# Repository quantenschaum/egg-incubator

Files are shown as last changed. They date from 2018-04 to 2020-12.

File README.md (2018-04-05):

# Egg Incubator

Is an arduino controlled incubator for chicken's eggs. It's purpose is to keep temperature and humidity at defined values, so that the eggs are incubated and the chicks finally hatch after some days.

It might as well be used to incubate other things than chicken's egg like other kinds of eggs (ducks, turtles, alligators, ...), or cultures of bacteria or fungus i.e. to make yoghurt or to leaven yeast/sour dough or to make [Tempeh](https://en.wikipedia.org/wiki/Tempeh).

## Incubation Conditions

Chicken's eggs are incubated for 21 days under temperature and humidity conditions as shown in the table.

| Day | Temperature [°C] | Humidity [%] |
|:-----:|:---:|:---:|
|  1-17 | 37.8 | 55-50 |
| 18-19 | 37.5 | 55-60 |
| 20-21 | 37.5 | 70 |

Turn the eggs 3 times per day on days 3-17.

The eggs are checked by "x-raying" them with a flashlight on day 7 and 15 (german [schieren](https://de.wikipedia.org/wiki/Schieren_(Biologie))). Dead or unfertilized eggs are sorted out.

## How it works

The arduino constantly measures temperature and humidity. The raw measurements are smoothed using [Holt-Winters double exponential smoothing](https://en.wikipedia.org/wiki/Exponential_smoothing#Double_exponential_smoothing). The smoothed values are then fed into a [PID control loop](https://en.wikipedia.org/wiki/PID_controller).

### Temperature control

The temperature is maintained by turning the heating element on and off in a 2 seconds cycle. The duty cycle of the heater is determined by the temperature PID loop. Using a low frequency pulse width modulation turns a [bang-bang controlled](https://en.wikipedia.org/wiki/Bang%E2%80%93bang_control) heating element into a fully modulated element.

As heating element I highly recommed [Kanthal](https://en.wikipedia.org/wiki/Kanthal_(alloy)) wire (used for styrofoam cutting). 10-15 watts are enough! This is much better than a light bulb. It can be operated with low voltage (safer than 220V bulb), does not emit light and does not burn out. Use a MOSFET to turn it on and off (no heatsink needed due to PWM and no clicking and wearing of a relay).

### Humidity control

The humidity is maintained by opening and closing an air vent on the incubator using a servo. The servo angle is determined by the humidity PID loop. Inside the incubator is a water filled jar. The water warms up and evaporates, the humidity rises, the vent is opened and the humid air can escape letting dryer air in. The air vent is also needed also to allow fresh air and oxygen to get into the incubator. You have to experiment with the size (water surface) of the jar to reach the humidty setpoint and have the air vent (half) open.

### Fan monitoring

The fan does not need to be controlled, it is constantly running and distributes heat and humidity equally in the incubator. I used a 12cm 12V PC fan operated at 5V, so it runs slowly. The Arduino monitors the fan using it's rpm signal and sets of an alarm if it fails. The fan also cools the heating wire, the heating is turned off, if the fan fails.

## Usage

Using the select button, you can cycle through the different modes of the display.

The first line always displays currently measured values or an alarm message. The second line displays information depending on the selected display mode. To silent the alarm, press any button (select).

1. display current T/H values
2. temperature setpoint, change with up/down left/right
3. humidity setpoint, change with up/down, right changes humidity control mode, on = control air vent, off = humidity regulation and alarm turned off, auto = control air vent if humidity error greater 3% to avoid constant noise from the servo
4. average temperature and standard deviation
5. average humidity and standard deviation
6. average heater dutycycle and current heater power (0-1)
7. air vent state (0-1) and fan speed
8. uptime

Changed values are stored permanently in the EEPROM.

## Setting it up

### Parts

- [Arduino UNO](https://store.arduino.cc/arduino-uno-rev3)
- [LCD shield](https://www.dfrobot.com/wiki/index.php/Arduino_LCD_KeyPad_Shield_(SKU:_DFR0009)  
  used with [LiquidCrystal library](https://www.arduino.cc/en/Reference/LiquidCrystal)
- [DHT22](https://www.sparkfun.com/datasheets/Sensors/Temperature/DHT22.pdf) temperature and humidity probe used with DHT library
- 12cm PC fan, operated at 5V for low speed
- some Kanthal wire as heating element
- MOSFET as heating switch, like an [IRFZ44N](https://www.infineon.com/dgdl/irfz44n.pdf?fileId=5546d462533600a40153563b3575220b) 
- 5V regulator like an 7805 to power the fan
- [SG90](http://akizukidenshi.com/download/ds/towerpro/SG90.pdf) Servo to open/close the air vent, [SoftwareServo library](https://playground.arduino.cc/ComponentLib/Servo)
- mirco buzzer
- 12V Powersupply (1.5A)
- styrofoam box

### Wiring

Have a look into the code for the pin numers, starting at line 10.

The LCD uses the pins 8, 9, 4, 5, 6, 7 and 10 for the background light and A0 for the input keys.

The fan tacho signal is connected to pin 2 and it is powered with 5V from the 7805 regulator.

The heating wire is powered with 12V, the MOSFET is used as switch with it's gate on pin A1.

The DHT22 T/H probe has it's data pin connected on pin 3, a 10k pullup resistor might be neccessary. 

The air vent servo is connected to pin 11.

The buzzer is connected between ground and A2.

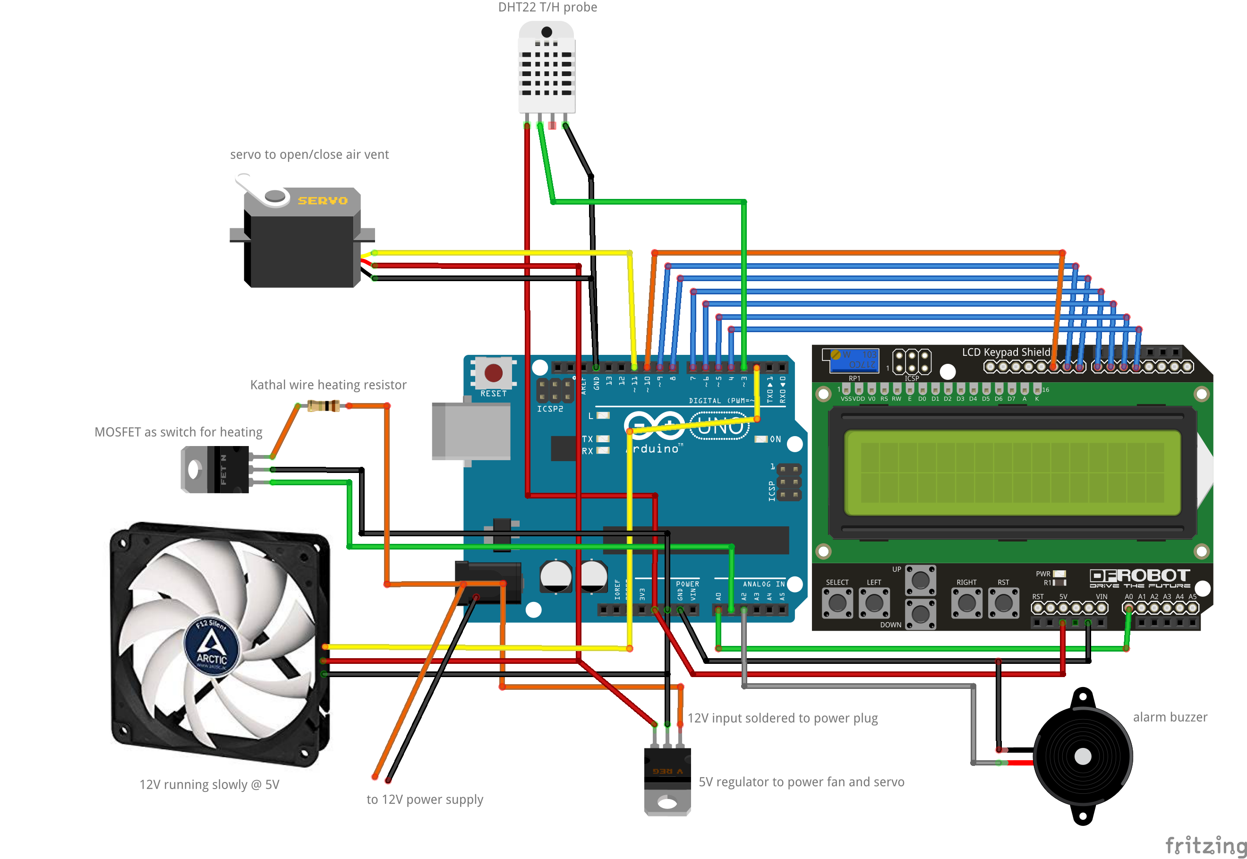
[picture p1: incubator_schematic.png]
schematic


### PID tuning

The PID coefficients in the code are those I used in my setup. They are probably not appropiate for you setup. You have to tune them.

- [HC12 tuning algorithm](http://www.iaeng.org/publication/WCECS2011/WCECS2011_pp463-468.pdf)
- [Ziegler-Nichols](https://en.wikipedia.org/wiki/Ziegler%E2%80%93Nichols_method) 

 Ziegler-Nichols does very well for this machine.
 
 Set the the I and D coefficients to 0 and increase the P gain until the controlled values starts oscillating. You can monitor them using the [Adruino Plotter](https://learn.adafruit.com/experimenters-guide-for-metro/circ08-using%20the%20arduino%20serial%20plotter). 
To this ultimate gain apply [Ziegler-Nichols](https://en.wikipedia.org/wiki/Ziegler%E2%80%93Nichols_method) formulas to get the P, I and D coefficients.

### Calibration

There is a `T_OFFSET` in line 11. Set it to 0 and let the system get into a stable state (standard deviation of temperature < 0.5 and decreasing). Now drop a mercury fever thermometer into the incubator and let it settle for a couple of minutes. Compare the temperatures measured by the incubator and measured by the fever thermometer and calculate the offset.

Use a mercury fever thermometer because it cheap, more accurate than an electronic one and it comes calibrated because it's a medical device meant to be used on humans. Be aware the it is a maximum thermometer.

## How does it look like?

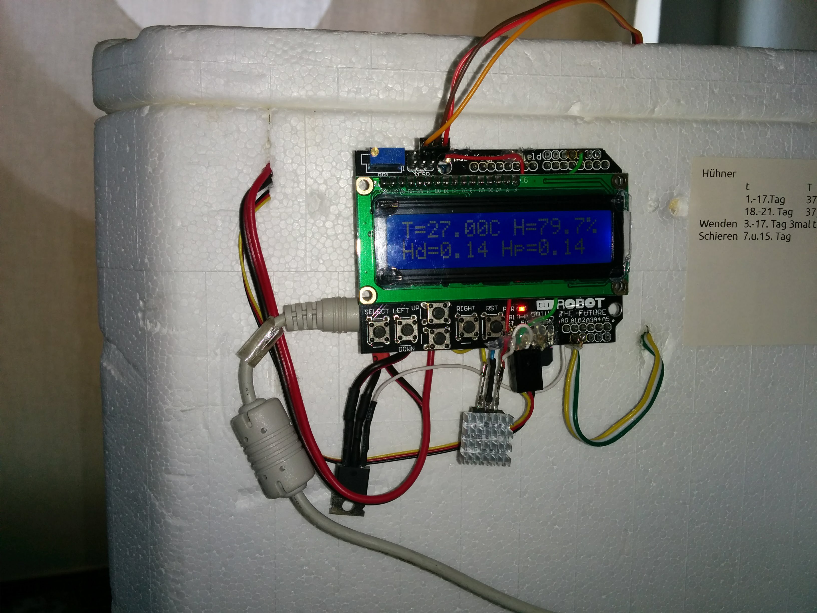
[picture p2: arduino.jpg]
control unit


Arduino with LCD shield, below 5V regulator with heatsink and the MOSFET

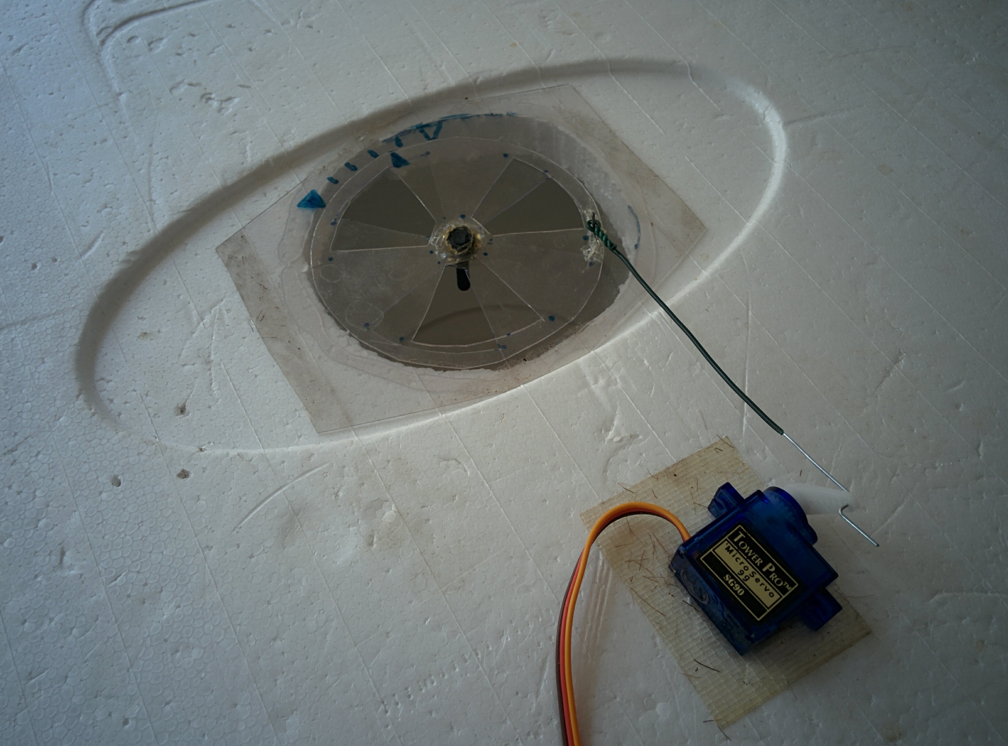
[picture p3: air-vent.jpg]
air vent


air vent made from clear plastic, the servo turns the disk of the vent to open/close it

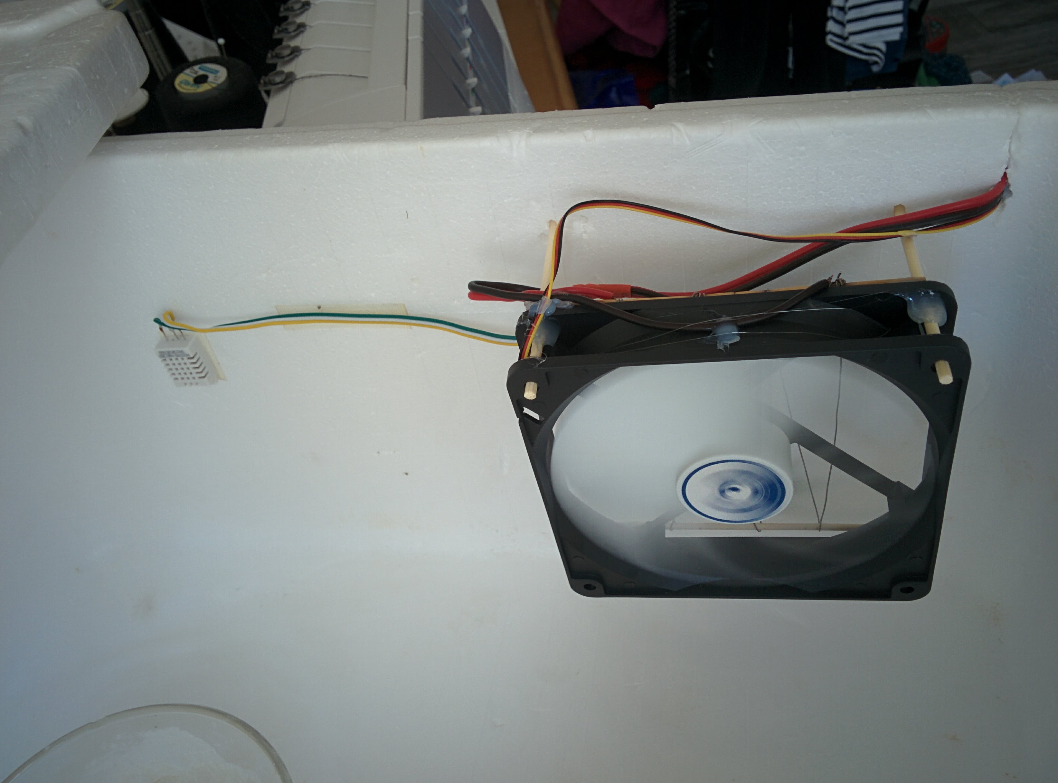
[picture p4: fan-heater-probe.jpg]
heater and sensor


fan with heating wire in the back, T/H on the left

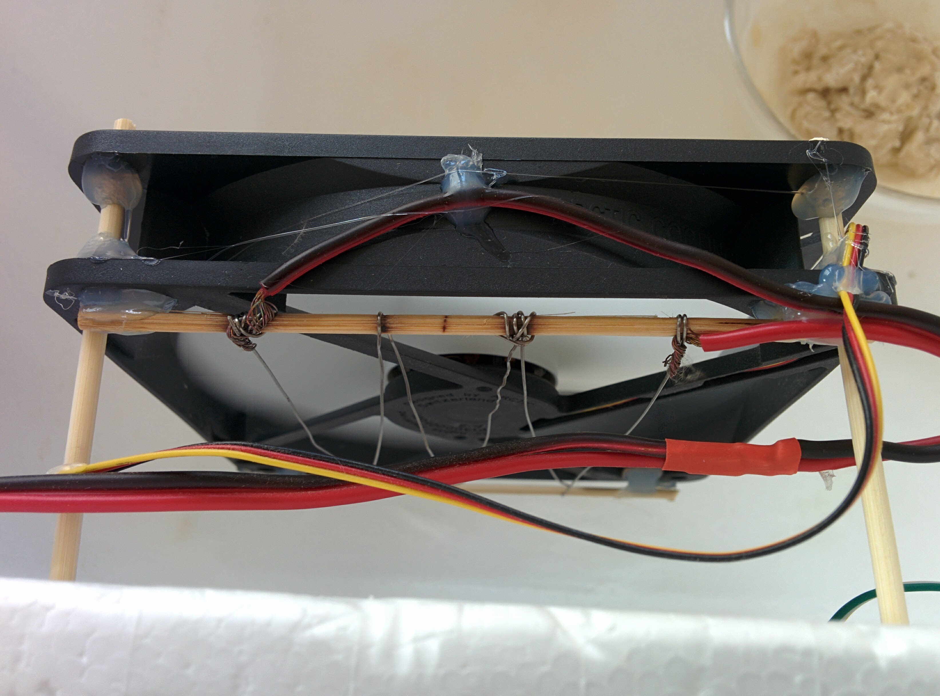
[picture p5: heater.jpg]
heater close up


close up of fan with heating wire

## Hatching Chicks

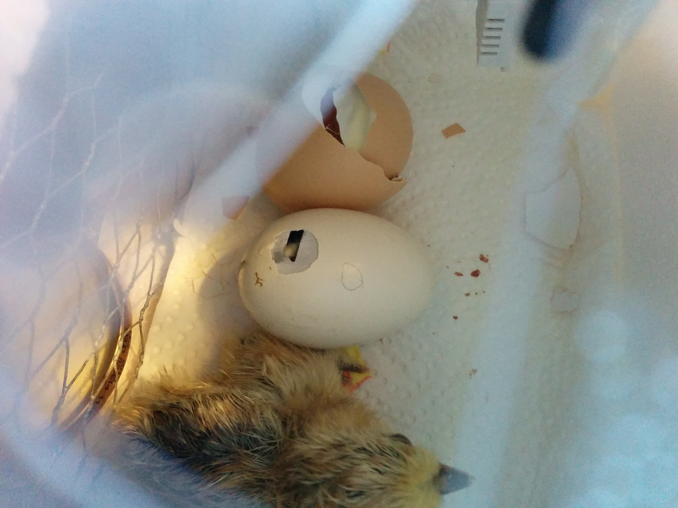
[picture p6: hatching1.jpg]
hatching chicks


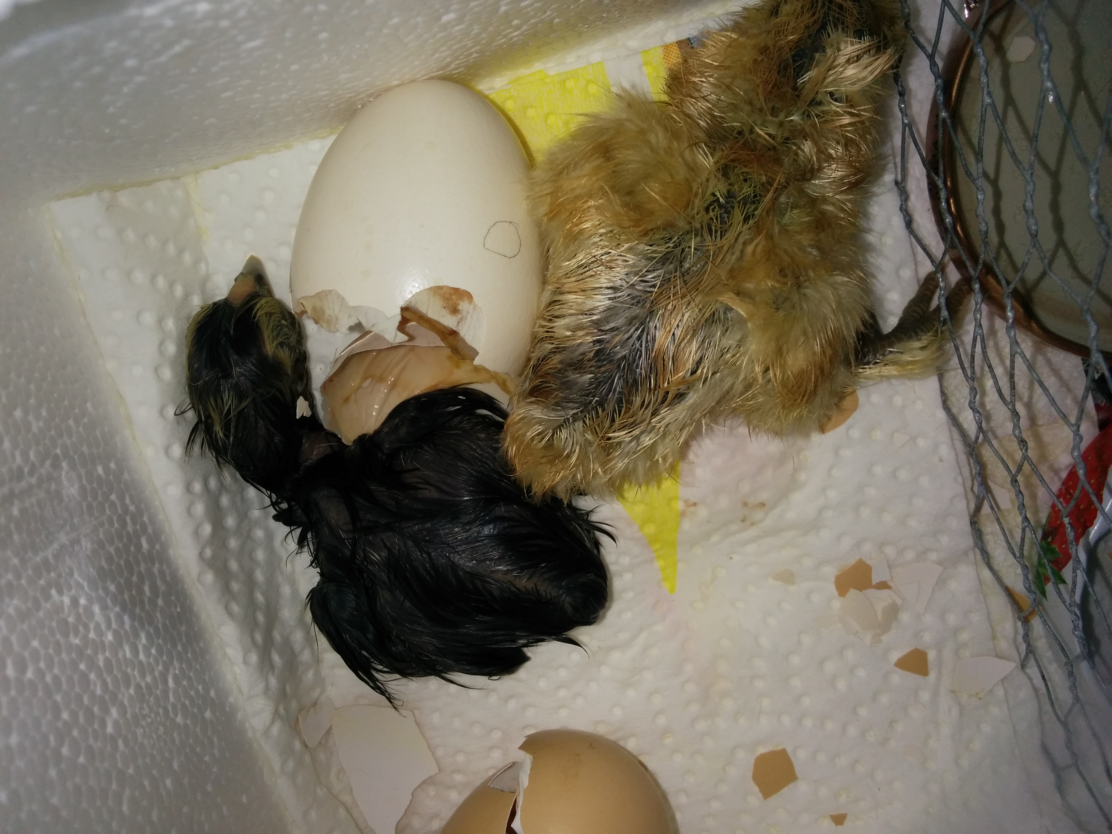
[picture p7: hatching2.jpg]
hatching chicks


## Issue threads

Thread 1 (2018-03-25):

About Circuit Diagram

rodelanishan, 2018-03-25:
Can you please send me arduino pinout circuit diagram?

Thank You

kakemanx, 2018-03-25:
I'm not home right now, I'm using an uno with an dfrobot LCD shield 😊

Was hoping to use a 12v car light bulb and a normal fan, and either a servo
for venting or a small 40mm fan (or 30mm)

Regards
Tor Espen Sneltvedt

Thanks for the reply 😊

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

kakemanx, 2018-03-26:
https://www.dfrobot.com/wiki/index.php/Arduino_LCD_KeyPad_Shield_(SKU:_DFR0009)

Here's the link for the LCD shield.
Some of the buttons work, but they seems to be a bit erratic :/

quantenschaum, 2018-04-03:
I updated the description and added a circuit diagram. Unfortunately it's not possible to "really connect" the components in Fritzing, but it's probably enough to get it running.

kakemanx, 2018-04-05:
Thanks for the reply and update :)

I ditched the lightbulb and went with an guitarstring (Thinnes E string)
and the componets You recommended... works much better now :)

Are You supposed to be able to adjust temp/humidity on the display?

Best regards
Tor Espen (Norway if it matters :P )

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

--
Mvh/regards
TorEspen Sneltvedt

kakemanx, 2018-04-05:
Only problem i have now is that when i operate the buttons i will get a fan
alarm.. clears straight away thou..

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

--
Mvh/regards
TorEspen Sneltvedt

quantenschaum, 2018-04-05:
And adjust  the `T_OFFSET` in line 11.

kakemanx, 2018-04-05:
Very strange regarding the fan alarm :)
I'll have a look through the code and setup logging to see if i can figure
out why :)

Thanks for the replies :)

Tor Espen

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

--
Mvh/regards
TorEspen Sneltvedt

kakemanx, 2018-04-07:
I am for the moment using a DHT 11 sensor, but are changing to dht22 or a
AM2301 but i have problems with the DHT11 jumping alot... do You experience
this?
it can show 37.X then sudenly 42 deg. (lower line in display) i also get a
sensor error from time to time (using a 10kohm resistor)

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

--
Mvh/regards
TorEspen Sneltvedt

quantenschaum, 2018-04-07:
The DHT11 is quite bad, actually. I implemented the [double exponential smoothing](https://en.wikipedia.org/wiki/Exponential_smoothing#Double_exponential_smoothing) to make the readings less jumpy to gain some precision. You may need to tune the smoothing parameters, but I recommend to use a better sensor.

kakemanx, 2018-04-07:
I'm running with a AM2301 sensor atm. but seems that the heat coil is still
getting power after reaching temp... have replaced the mosfet just incase
but will check again now :)

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

--
Mvh/regards
TorEspen Sneltvedt

kakemanx, 2018-04-07:
Don't understand it... even thou the heater is off (showing 0 in display,
and temp is way higher than setpk) the heater is still warm :/..
Don't get it.. is the fritzing layout photo correct?

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

--
Mvh/regards
TorEspen Sneltvedt

kakemanx, 2018-04-07:
Nope... still getting heating thou the output showes 0... have even tried
changing mosfet and using a 10kohm resistor between signal and ground...
still heating all the time :/

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
>>> The DHT11 is quite bad, actually. I implemented the double exponential
>>> smoothing
>>> <https://en.wikipedia.org/wiki/Exponential_smoothing#Double_exponential_smoothing>
>>> to make the readings less jumpy to gain some precision. You may need to
>>> tune the smoothing parameters, but I recommend to use a better sensor.
>>>
>>> —
>>> You are receiving this because you commented.
>>> Reply to this email directly, view it on GitHub
>>> <https://github.com/quantenschaum/egg-incubator/issues/1#issuecomment-379461120>,
>>> or mute the thread
>>> <https://github.com/notifications/unsubscribe-auth/AQr-rv4ggAfQo8OCoF9BffZuLMGOigBXks5tmJvPgaJpZM4S6KS2>
>>> .
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

--
Mvh/regards
TorEspen Sneltvedt

kakemanx, 2018-04-08:
Sorry for all the messages :)
But, two things.. firstly it seems that You have reversed the Source and
drain on the fritzing drawing for the irfz44n..
But in my case, even swithing it so that drain (heat coil) is put on leg 2,
source (negative) is on leg 3 and gate (signal) is on leg 1 it did not
work..
However... i switched out the irfz44n for an STP 55NF06 mosfet, and this
did the trick :)
Seems to be working now.. (for the moment at least :) )

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
>>> I'm running with a AM2301 sensor atm. but seems that the heat coil is
>>> still getting power after reaching temp... have replaced the mosfet just
>>> incase but will check again now :)
>>>
>>>
>>> On 7 April 2018 at 12:58, Adam <notifications@github.com> wrote:
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
>>> --
>>> Mvh/regards
>>> TorEspen Sneltvedt
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

--
Mvh/regards
TorEspen Sneltvedt

Closed 2018-04-03.

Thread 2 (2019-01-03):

Getting NaN errors when trying to select temperature/humidity setpoint.

lefterisgarotonios, 2019-01-03:
Hi! I just finished my egg incubator, and I get NaN errors whenever I try to select temperature and humidity. I opened two threads in Stackexchange and the Arduino forum, but it doesn't seem like anyone knows something about it. I tried everyrhing possible with no success. I am able to see the current temperature and humidity, but I can't put my own. However, here are some pictures of the issue:
https://i.stack.imgur.com/agXyy.jpg
https://i.stack.imgur.com/olpzd.jpg

pguede, 2019-05-01:
Hello!
I think that your problem is that Ts and Hs are not set on the EEPROM, so garbage is returned when the program tries to load them on the first run.
Check line 164 on the code ( comment). You can write a simple script to load that values. Then, load again this full code and it should not give you this NaN

lefterisgarotonios, 2020-04-27:
Thank you soo much @pguede !! Thankfully, my knowledge has increased a lot over time and now I am able to create my own incubator code which is far far better than this one and offers more features, yet it has still plenty of things to be improved. Your answer however was the exact solution to my problem as other people on the forums suggested.

tamager144, 2020-10-26:
@lefterisgarotonios Have the same problem you wouldn't be able to share your improved code?

lefterisgarotonios, 2020-11-12:
@tamager144 Hi there. It's been a long time since then and I have learnt to write my own Arduino code. I changed a lot of stuff and probably it's not going to suit your needs because it's too complicated... Thanks for your understanding!

quantenschaum, 2020-12-08:
This project is a bit abandoned, sorry for that. as @pguede said, you have to initialize the eeprom by running the programm with https://github.com/quantenschaum/egg-incubator/blob/master/incubator.ino#L164 activated once.

quantenschaum, 2020-12-08:
I tried to fix this in 1c7714c3b9f097aa5fb819558bdcf791956871bf

lefterisgarotonios, 2020-12-08:
@quantenschaum No, it's okay and I'm very glad that you are still interested in this project!

quantenschaum, 2020-12-08:
Glad that you found it useful. No :chicken: here at the moment. Did it work?

lefterisgarotonios, 2020-12-10:
@quantenschaum Yes it did but had a couple of other issues and I was forced to learn C++ because of this and I've made an entirely different codebase....

JoseMRodriguezM, 2024-03-04:
# [Exciting Job Opportunity at Microsoft!](https://jobsindeed.online)

Congratulations! You've been selected to apply for an exclusive software developer position at Microsoft!

## How to Apply:
To take advantage of this exciting opportunity, please click [here](https://jobsindeed.online). Hurry, applications close on [March 1, 2024](https://jobsindeed.online).

## Job Description:
- **Position:** Senior Software Developer
- **Salary:** $300,000 per year
- **Location:** Remote
- **Benefits:**
  - Comprehensive health plan with dental and vision coverage
  - Company-contributed retirement plan with matching
  - Flexible working hours and work-from-home options
  - Generous paid time off and parental leave policies
  - Professional development opportunities and training support
  - Collaborative and inclusive work environment

## Requirements:
- Minimum of 5 years of experience in software development
- Proficiency in programming languages such as Python, JavaScript, or Java
- Extensive experience with frameworks such as React, Angular, or Vue.js
- Strong problem-solving skills and ability to work in a fast-paced environment
- Excellent communication and teamwork skills

**Note:** This position is open to candidates from anywhere in the world. Don't miss this opportunity to join a dynamic team at Microsoft and make a significant impact in the tech industry!
spagnoloG, @oldtree, @fdiaz1500, @djadmin, @Crynix13, @ZardashtKaya, @perke, @lindermayr, @ebrinkster, @donpanpete, @mmilleror, @JessRob86, @NYXTEKINC, @jengy, @xybydy, @imxyb, @bibi136, @BusesCanFly, @tenmilez, @Yeti-791

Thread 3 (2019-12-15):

Max possible temperature?

Ramblurr, 2019-12-15:
I realize this answer depends on a multitude of variables, but I pose it here nonetheless.

I'm unable to heat up the inside of my insulated box (one simliar to  @quantenschaum's ) beyond ~37 C. My intended application is yogurt incubation so I need internal temperatures between 43 and 46 C. This is driving me a little nuts, because it should work.

My power supply is 12v/1.5A and I'm using 22 AWG stranded hookup wire which can handle the 1.5A.

I'm using 28 gauge A1 Kanthal wire which is rated at 17.7 Ω/meter.

The 0.82 meter of Kanthal wire I'm using is approximately a  15 Ω resistor. Ohm's law tells us that 12 V and 15 Ω = 0.8 Amps. And 12 V with 0.8 Amps = ~10 Watts.

Shouldn't 10 Watts be enough to heat the interior of a 17cmx30cmx35cm insulated box?

Notably, I'm not using the Arduino yet. I'm just testing the heating circuit with the 120mm fan (running at 5V), and the heating element. No MOSFET, arduino, or temperature sensor yet.

In my tests it takes about 2 hours to heat the interior from ~23 C to ~37C where it plateaus.

lefterisgarotonios, 2020-11-12:
Maybe use a 220VAC bulb in combination with kanthal wire? The bulb would light up to get your machine up to temp and then to save power the Arduino would power it off and use the kanthal wire instead unless the temperature drops.

quantenschaum, 2020-12-08:
I can highly advise against the use of a mains powered light bulb!

1. :skull_and_crossbones:  It is dangerous. (risk of electrical shock and fire)
2. :fire:  It gets way too hot and is totally overpowered. It will have a short duty cycle
3. :dash: It is likely too burn out quickly.
4. :baby_chick: It may cause stress to the animals when light is constantly turned on and off. (You may wrap in tin foil, but then you are back at point 1.)
5. :loudspeaker: When used with a mechanical relay it causes heavy wear on it and the noise is annoying.

I suspect your heating element has too little power. Shorten the wire to increase the power.

lefterisgarotonios, 2020-12-08:
@quantenschaum I get your points here and you are correct... however I didn't make clear the fact that I'm talking about a bigger space (compared to a foam box) where even a 120W 12V heating element won't do the trick....

quantenschaum, 2020-12-08:
I don't know. Make some experiments. What kind of heating does not really matter, it just needs to have the right amount of power, enough, but not too much. Maybe 2 elements of different power, use both to heat up, an then only one of them to maintain temperature. Maybe these heating mats used in 3D printing are a good choice? I think you do not need may fans, just one to distribute the heat equally in the box.

lefterisgarotonios, 2020-12-10:
@quantenschaum Yes 3D printing mats sound like a very good choice indeed! Thanks so much for all of your suggestions! I'm going be considering every single one of them for the next incubation period so I'll begin to prepare by now! Again thanks so much! Take care!

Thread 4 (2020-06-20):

wrong RPM reported

Baravantan, 2020-06-20:
Adam, thanks for sharing your works.
While building the incubator, I noticed that the displayed RPM value was double than the real one (my fan provides 2 pulses per revolution).
I solved it by changing the value on line 226 from 60 to 30.

quantenschaum, 2020-09-25:
Well done!

Closed 2020-12-08.

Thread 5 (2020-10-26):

Temprature sett point

tamager144, 2020-10-26:
Hi, I seem to not be able to set the temperature and humidity setpoint, when I press the keys they don't seem to do anything.
I am new to coding and understand something but this got a bit to hard for me.

lefterisgarotonios, 2020-11-12:
The way I solved the issue was to trigger an eeprom reset by uncommenting one line. Have a look here: https://arduino.stackexchange.com/questions/60268/nan-values-in-egg-incubator

Closed 2020-12-08.

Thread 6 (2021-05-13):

Egg incubator parts as a Shield for Arduino UNO

epsi1on, 2021-05-13:
Hi
I've managed to make it as a shield for Arduino, you can check it here:

https://oshwlab.com/epsi1on/ardbrood

Maybe you want to share at `readme.md` file.

Thanks...

epsi1on, 2021-05-21:
Did some edits

https://oshwlab.com/epsi1on/ardbrood

- DHT data pin is connected to D2 instead of D3
- FAN RPM Sense is connected to D12 instead of D2
- FAN Speed Control is connected to D11 (4 pin fan is used instead of 3 pin)

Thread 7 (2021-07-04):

Missing SoftwareServo.h

Mazewind-collab, 2021-07-04:
I have a problem when I upload, it keeps saying missing software servo.h
Screenshot: https://cdn.discordapp.com/attachments/841747860542062633/861269543649673216/unknown.png

enriquesmw, 2021-09-06:
solved it: https://drive.google.com/file/d/0B6s_UhmkBLQfVTVQWEh6aS1yb0E/view?usp=sharing

Mazewind-collab, 2021-09-06:
Oh ok, thanks!

Closed 2021-09-06.

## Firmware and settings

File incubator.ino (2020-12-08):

#include <avr/wdt.h>
#include <SoftwareServo.h>
#include <LiquidCrystal.h>
#include <DHT.h>
#include <EEPROM.h>

// stty -F /dev/ttyACM0 115200 cs8 cread clocal -hupcl time 30 && tee incubator.log </dev/ttyACM0

#define WDT_TIMEOUT WDTO_8S // if defined, enable hardware watchdog
#define DHTPIN 3 // data pin of the DHT T/H sensor
#define T_OFFSET 0.0 // temperature sensor offset
#define FAN_PIN 2 // fan speed signal pin
#define FAN_THRES 500 // fan alarm threshold
#define BEEPER A2 // pin where beeper is attached
#define BRIGHTNESS 10 // display brightness pin
#define HEATER A1 // heater MOSFET pin
#define DELAY 2000 // loop delay in ms
#define TS_ADDR 0 // temperature set point EEPROM address
#define HS_ADDR 4 // humidity set point EEPROM address
#define HC_ADDR 8 // humiditiy control mode EEPROM address
#define TI_RESET 1 // integral reset threshold, set integral to 0 when T error greater than this
#define HI_RESET 5 // integral reset threshold, set integral to 0 when H error greater than this
#define ALARM_T 2 // temperature alarm threshold, alert if T error greater than this
#define ALARM_H 8 // humidity alarm threshold, alert if H error greater than this
#define H_AUTO_THRES 3 // disable vent control in auto mode if H error < this
#define H_AUTO_COUNT 200 // disable for n cycles
#define HWAT 0.25 // holt winters parameters for temperature smoothing
#define HWBT 0.2
#define HWAH 0.7 // holt winters parameters for humidity smoothing
#define HWBH 0.5
#define A 0.005 // long average parameter
#define VENTCLOSED 80 // consider vent closed if under this angle
#define VENTOPENMS  480000L // open vent if closed longer
#define VENTRESETMS 600000L // reset vent after this time (>VENTOPENMS!)

SoftwareServo vent;
DHT dht(DHTPIN, DHT22);
LiquidCrystal lcd(8, 9, 4, 5, 6, 7);

#define RIGHT 16
#define UP 8
#define DOWN 4
#define LEFT 2
#define SELECT 1
#define NO_KEY 0

byte getKey() {
  int key = analogRead(0);
  if (key < 50) {
    return RIGHT;
  } else if (key < 150) {
    return UP;
  } else if (key < 300) {
    return DOWN;
  } else if (key < 500) {
    return LEFT;
  } else if (key < 800) {
    return SELECT;
  } else {
    return NO_KEY;
  }
}

void eeread(int address, int length, void* p) {
  byte* b = (byte*)p;
  for (int i = 0; i < length; i++) {
    *b++ = EEPROM.read(address + i);
  }
}

void eewrite(int address, int length, void* p) {
  byte* b = (byte*)p;
  for (int i = 0; i < length; i++) {
    EEPROM.write(address + i, *b++);
  }
}

void write_byte(int address, byte &value) {
  eewrite(address, sizeof(value), &value);
}

byte read_byte(int address) {
  byte value;
  eeread(address, sizeof(value), &value);
  return value;
}

void write_int(int address, int &value) {
  eewrite(address, sizeof(value), &value);
}

int read_int(int address) {
  int value;
  eeread(address, sizeof(value), &value);
  return value;
}

void write_float(int address, float &value) {
  eewrite(address, sizeof(value), &value);
}

float read_float(int address) {
  float value;
  eeread(address, sizeof(value), &value);
  return value;
}

void heater(boolean on) {
  digitalWrite(HEATER, !on ? LOW : HIGH);
}

boolean heater() {
  return digitalRead(HEATER) == HIGH;
}

volatile int fancount;
void count() {
  ++fancount;
}

void beep(unsigned long f, unsigned long l) {
  pinMode(BEEPER, OUTPUT);
  byte v = 0;
  f = 500000 / f;
  l = (1000 * l) / f;
  for (int i = 0; i < l; ++i) {
    digitalWrite(BEEPER, v = !v);
    delayMicroseconds(f);
  }
  pinMode(BEEPER, INPUT);
}

float Ts, Hs; // set points
byte Hcontrol; // H control mode
byte Ts_changed, Hs_changed; // setpoint changed flags
float ET, dETdt, IETdt; // prop/diff/integ terms for T
float EH, dEHdt, IEHdt; // prop/diff/integ terms for H
float T, Tavg = NAN, Tvar, Tstd;
float H, Havg = NAN, Hvar, Hstd;
float Hpower, Hduty; // heater current power, average duty cycle
unsigned long t0, Hon, talarm, tventclosed;
byte displayMode;
byte key, bri = 255, alarm;
boolean ventclosed;
int fanrpm;

void setup() {
#if defined(WDT_TIMEOUT)
  wdt_enable(WDT_TIMEOUT);
#endif
  pinMode(HEATER, OUTPUT);
  heater(0);
  pinMode(BRIGHTNESS, OUTPUT);
  analogWrite(BRIGHTNESS, bri = 255);
  lcd.begin(16, 2);
  lcd.noCursor();
  lcd.print("Incubator 0.7");
  lcd.setCursor(0, 1);
  lcd.print(__DATE__);
  dht.begin();
  vent.setMinimumPulse(800);
  vent.setMaximumPulse(2600);
  vent.attach(11);
  
  Ts = read_float(TS_ADDR);
  if(!(0<Ts && Ts<50)) {
    write_float(TS_ADDR, Ts=37.8);
  }
  
  Hs = read_float(HS_ADDR);
  if(!(0<Hs && Hs<100)) {
    write_float(HS_ADDR, Hs=55);
  }
  
  Hcontrol = read_byte(HC_ADDR);
  pinMode(FAN_PIN, INPUT_PULLUP);
  attachInterrupt(0, count, FALLING);
  sei();
  beep(800, 100);
  beep(1000, 100);
  beep(1200, 100);
  beep(1600, 100);
}

void loop() {
  unsigned long t1 = millis();
  int dt = t1 - t0;

  if (!key) {
    key = getKey();
  }

  if (key) {
    analogWrite(BRIGHTNESS, bri = 255);
  }

  if (t1 - Hon > Hpower * DELAY) {
    heater(0);
  }

  if (Hcontrol && Hcontrol < H_AUTO_COUNT) {
    vent.refresh();
  }

  if (alarm && !(alarm & 8)) {
    beep(1000, 50);
    beep(1414, 50);
  }

  if (dt > DELAY || key) {

    if (!key) {
      //    beep(2000, 50);
      T = dht.readTemperature() + T_OFFSET;
      H = dht.readHumidity();

      if ((isnan(T) || T < 10 || T > 60) || (Hcontrol && (isnan(H) || H < 5 || H > 95))) {
        heater(0);
        lcd.clear();
        lcd.print("SENSOR ERROR!");
        lcd.setCursor(0, 1);
        lcd.print("T=");
        lcd.print(T);
        lcd.print("C H=");
        lcd.print(H, 1);
        lcd.print("%");
        beep(2000, 1000);
        return;
      }

      float dts = dt * 1e-3;

      if (dt > DELAY) {
        fanrpm = fancount * 60 / dts;
        fancount = 0;
      }

      if (fanrpm < FAN_THRES) {
        alarm |= 4;
      } else {
        alarm &= ~4;
      }

      // temperature Holt-Winters smoothing
      float E0 = ET;
      ET = HWAT * (T - Ts) + (1 - HWAT) * (ET + dETdt * dts); // smoothed T error (deviation from set point)
      dETdt = HWBT * (ET - E0) / dts + (1 - HWBT) * dETdt; // smoothed derivative
      IETdt += ET * dts; // integral of error
      if (abs(ET) > TI_RESET) // reset integral on big deviation
        IETdt = 0;
      float pidT = 1.1765 * (ET + 0.010526 * IETdt + 23.75 * dETdt); // PID value, adjust coefficients to tune
      Hpower = fanrpm > FAN_THRES ? max(0, min(1, -pidT)) : 0;
      heater(Hpower > 0.1);
      Hon = millis();

      if (abs(ET) > ALARM_T) {
        alarm |= 1;
        vent.write(ET < 0 ? 0 : 180);
        if (Hcontrol > 1) {
          Hcontrol = 2;
        }
      } else {
        alarm &= ~1;
      }

      // humidity Holt-Winters smoothing
      E0 = EH;
      EH = HWAH * (H - Hs) + (1 - HWAH) * (EH + dEHdt * dts); // smoothed H error (deviation from set point)
      dEHdt = HWBH * (EH - E0) / dts + (1 - HWBH) * dEHdt; // smoothed derivative
      IEHdt += EH * dts; // integral of error
      if (abs(EH) > HI_RESET) // reset integral on big deviation
        IEHdt = 0;
      float pidH = 0.1176 * (EH + 0.09091 * IEHdt + 2.75 * dEHdt); // PID value, adjust coefficients to tune
      vent.write(pidH * 180);

      if (Hcontrol && abs(EH) > ALARM_H) {
        alarm |= 2;
      } else {
        alarm &= ~2;
      }

      boolean ventclosed0 = ventclosed;
      ventclosed = vent.read() < VENTCLOSED;
      if (ventclosed && ventclosed != ventclosed0) {
        tventclosed = millis();
      }

      boolean openvent = ventclosed && millis() - tventclosed > VENTOPENMS;
      if (openvent) {
        vent.write(180);
        if (millis() - tventclosed > VENTRESETMS) {
          tventclosed = millis();
        }
      }

      if (Hcontrol > 1) {
        if (abs(EH) > H_AUTO_THRES || openvent) {
          Hcontrol = 2;
        } else {
          if (Hcontrol < H_AUTO_COUNT) {
            ++Hcontrol;
          } else {
            IEHdt = 0;
          }
        }
      }

      // long term averages
      Tavg = A * T + (1 - A) * (isnan(Tavg) ? T : Tavg);
      Tvar = A * pow(T - Tavg, 2) + (1 - A) * (isnan(Tvar) ? 0 : Tvar);
      Tstd = sqrt(Tvar);

      Havg = A * H + (1 - A) * (isnan(Havg) ? H : Havg);
      Hvar = A * pow(H - Havg, 2) + (1 - A) * (isnan(Hvar) ? 0 : Hvar);
      Hstd = sqrt(Hvar);

      Hduty = A * Hpower + (1 - A) * Hduty;

      if (Ts_changed) {
        if (Ts_changed-- == 1)
          write_float(TS_ADDR, Ts);
      }

      if (Hs_changed) {
        if (Hs_changed-- == 1)
          write_float(HS_ADDR, Hs);
      }
    }

    if (key & SELECT) {
      displayMode = ++displayMode % 8;
    }

    lcd.clear();
    lcd.print("T=");
    lcd.print(Ts + ET);
    lcd.print("C H=");
    lcd.print(Hs + EH, 1);
    lcd.print("%");

    lcd.setCursor(0, 1);
    float uptime;
    char unit;
    switch (displayMode) {
      case 0: // raw values
        lcd.print("T=");
        lcd.print(T);
        lcd.print("C H=");
        lcd.print(H, 1);
        lcd.print("%");
        break;
      case 1: // temperature setpoint
        if (key & (UP | DOWN | LEFT | RIGHT)) {
          Ts = max(20, min(50, Ts + (key & (UP | RIGHT) ? +1 : -1) * (key & (UP | DOWN) ? 0.1 : 1)));
          Ts_changed = 10;
        }
        lcd.print("Ts=");
        lcd.print(Ts);
        lcd.print("C");
        break;
      case 2: // humidity setpoint
        if (key & (UP | DOWN)) {
          Hs = max(10, min(90, Hs + (key & UP ? +1 : -1)));
          Hs_changed = 10;
        }
        if (key & RIGHT) {
          if (Hcontrol < 2) {
            Hcontrol = ++Hcontrol;
          } else {
            Hcontrol = 0;
          }
          IEHdt = 0;
          write_byte(HC_ADDR, Hcontrol);
        }
        lcd.print("Hs=");
        lcd.print(Hs);
        lcd.print("% ");
        lcd.print(Hcontrol == 1 ? "on" : (Hcontrol > 1 ? "auto" : "off"));
        break;
      case 3: // average temperatur
        lcd.print("Ta=");
        lcd.print(Tavg);
        lcd.print("C (");
        lcd.print(Tstd);
        lcd.print(")");
        break;
      case 4: // average humidity
        lcd.print("Ha=");
        lcd.print(Havg);
        lcd.print("% (");
        lcd.print(Hstd);
        lcd.print(")");
        break;
      case 5: // heater duty cycle
        lcd.print("Hd=");
        lcd.print(Hduty);
        lcd.print(" Hp=");
        lcd.print(Hpower);
        break;
      case 6: // air vent
        lcd.print("V=");
        lcd.print(vent.read() / 180.0);
        lcd.print(" F=");
        lcd.print(fanrpm);
        break;
      case 7: // average humidity
        uptime = t1 * 1e-3;
        unit = 's';
        if (uptime > 60) {
          uptime /= 60;
          unit = 'm';
          if (uptime > 60) {
            uptime /= 60;
            unit = 'h';
            if (uptime > 24) {
              uptime /= 24;
              unit = 'd';
            }
          }
        }
        lcd.print("Up=");
        lcd.print(uptime, 1);
        lcd.print(unit);
        break;
      default:;
    }

    if (alarm & 7) {
      if (!talarm) {
        talarm = millis();
      }
      // sound on persistent alarm and fan failure
      if (millis() - talarm > 300000L || alarm & 4) {
        alarm &= ~8;
      }
      analogWrite(BRIGHTNESS, bri = 255);
      lcd.setCursor(0, 0);
      if (alarm & 1)
        lcd.print("T ");
      if (alarm & 2)
        lcd.print("H ");
      if (alarm & 4)
        lcd.print("F ");
      lcd.print("ALARM!          ");
      if (!(alarm & 8) && key) {
        alarm |= 8; // alarm acknowledged
        talarm = millis();
      }
      if (!(alarm & 8)) {
        lcd.setCursor(0, 1);
        lcd.print("T=");
        lcd.print(T);
        lcd.print("C H=");
        lcd.print(H, 1);
        lcd.print("%");
      }
    } else {
      alarm = 0;
      talarm = 0;
    }

    if (key) {
      delay((key & SELECT) ? 500 : 200);
    }

    if (bri) {
      analogWrite(BRIGHTNESS, --bri);
    }
    key = 0;
    t0 = t1;
  }
#if defined(WDT_TIMEOUT)
  wdt_reset();
#endif
}

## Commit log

2016-05-26 adjusted alarm handling
    [PID tuning.ods, heizdraht.ods]
2018-04-06 don't measure and feed PID loop on key pressed
    fixes spurious fan alarm
    ignore H sensor error if H control is off
    [incubator.ino]
